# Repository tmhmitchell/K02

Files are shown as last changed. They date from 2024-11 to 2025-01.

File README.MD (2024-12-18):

<p float="center">
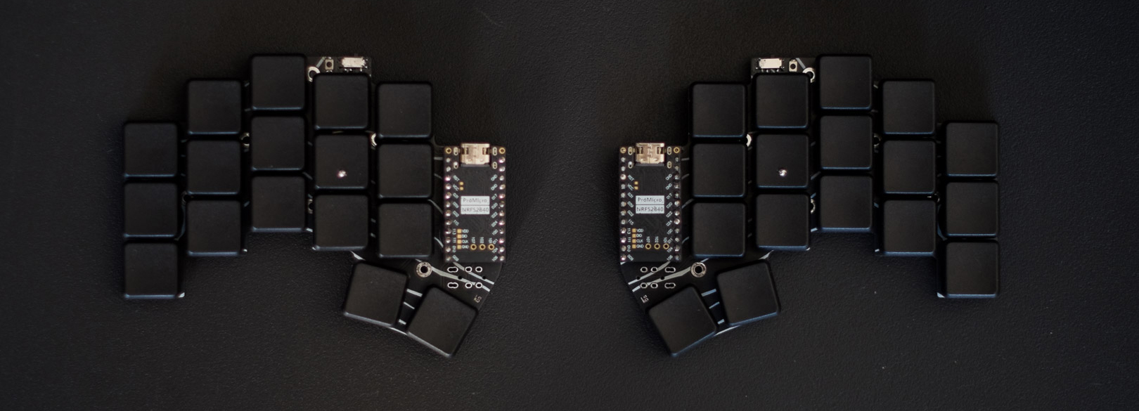
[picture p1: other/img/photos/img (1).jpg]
   
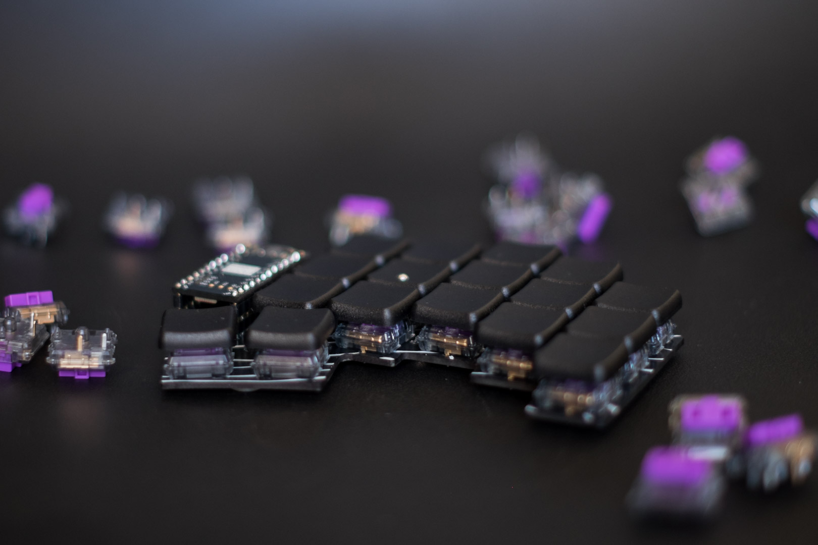
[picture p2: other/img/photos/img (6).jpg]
   
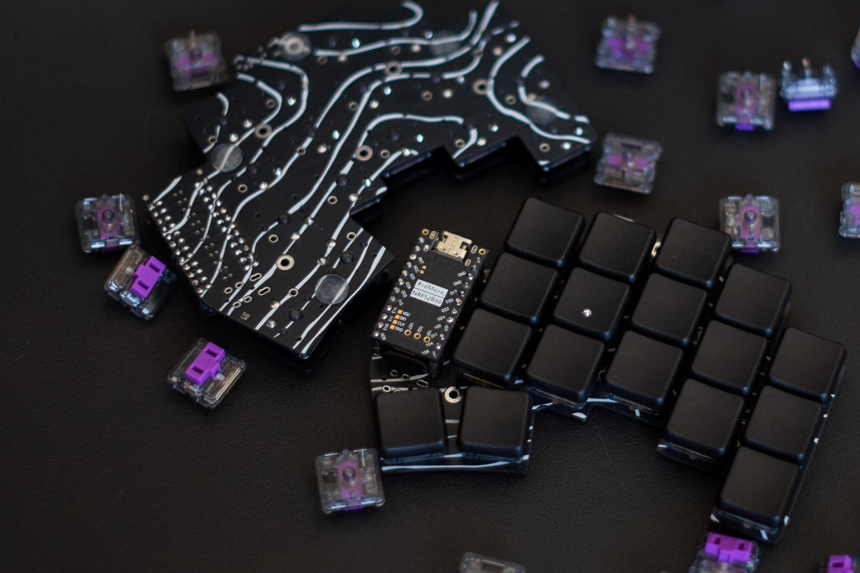
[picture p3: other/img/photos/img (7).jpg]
   
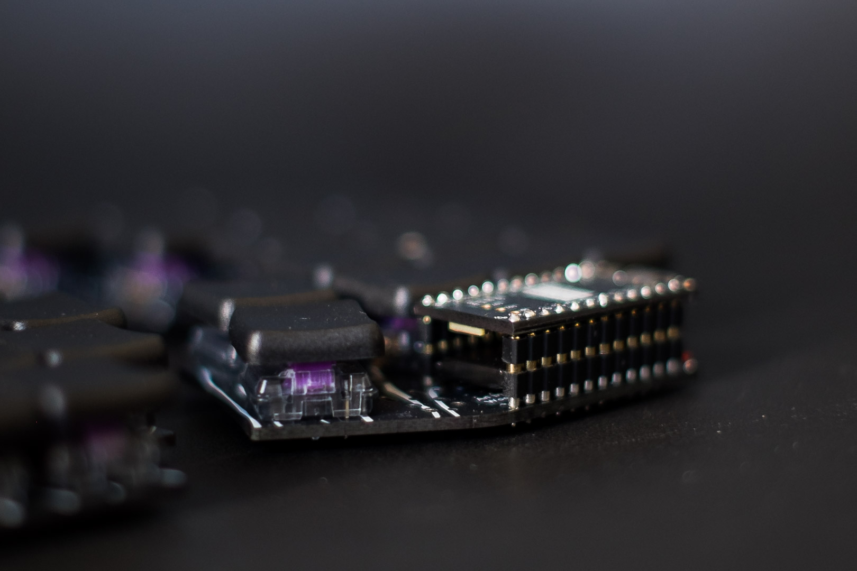
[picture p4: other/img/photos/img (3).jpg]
   
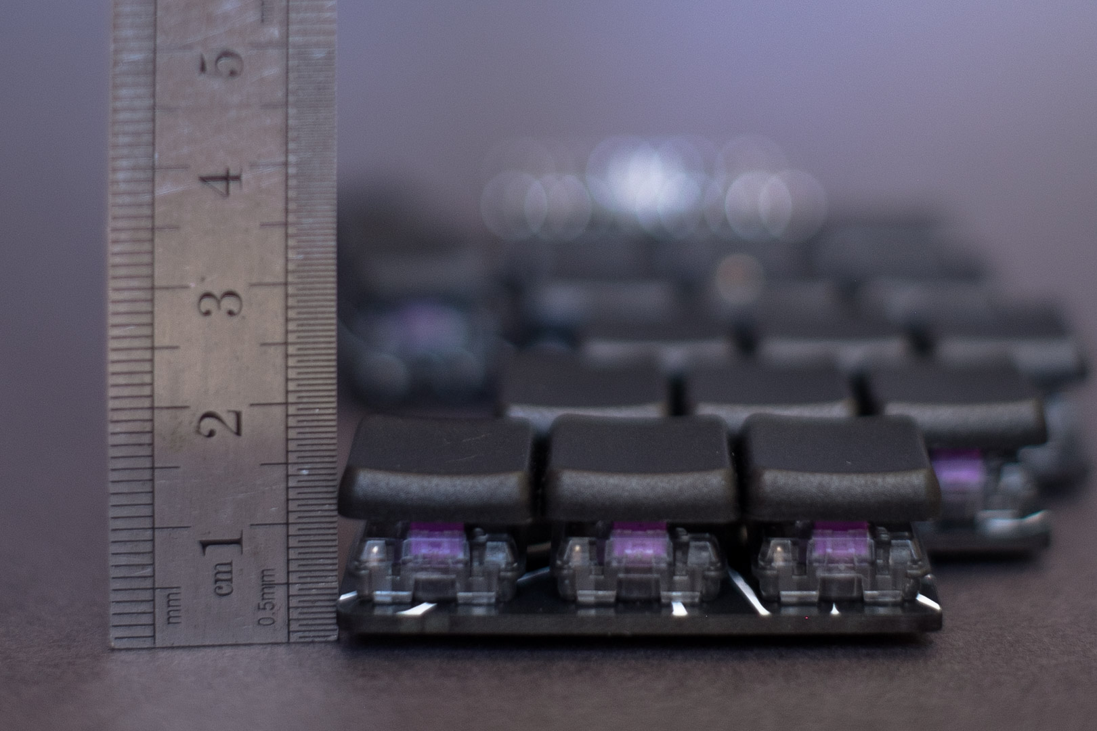
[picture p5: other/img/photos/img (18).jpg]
  
</p>

<p float="left">
  
</p>

**Less, but better.** - Dieter Rams

After seeing the [Ferris Sweep](https://github.com/davidphilipbarr/Sweep) for the first time I've fallen in love, but as a designer I cannot accept the things the way they are. So I've done some experimentation with it.

I changed the overall form of the board so it can be a little bit more compact and be a canvas for expression in the matter of case design

This is a parcial redesign of the [Ferris Sweep 2 half-swept](https://github.com/davidphilipbarr/Sweep). In other words this is a:

- 34 keys.
- Diodeless.
- Low profile.
- Non-hotswap.
- Reversible PCB.
- Column staggered.
- [Tenting puck](https://splitkb.com/products/tenting-puck) compatible.
- Wireless and wired capable.
- Choc MBK spaced (17,5mm x 16,5mm).
- Cheaper than the [cheapino](https://github.com/tompi/cheapino) (at the time of the build).

### What have been done:

- Change PCB overall form.
- Add support screw holes.
- Add teardrop on solder joints.
- Reposition of the reset and power switch.
- Do an extensive and compreensive [assembly manual](/other/manuals/k02-assembly-manual.pdf).
- Create an alternative version with `USB-C` instead of `TRRS`.
- Add commissioned art by the brazilian artist [Aline Dal Pont](https://www.instagram.com/manifesto.efemero/).
- Remove all the informative silk graphics for a better looking board.

### What I may do<sup>1</sup>:

- Change the `USB-C` location.
- Make it compatible with choc V2 switches.
- Change the `USB-C` connector to mid-mount 6p.
- Design some _minimalist_ and _low profile_ cases.
- Create an 36 keys pcb with breakpoints/mousebites.
- Add a variation with choc spacing for [CFX keycaps](https://kbd.news/CFX-keycap-1553.html) (16,5mm x 16,5mm).

> <sup>1</sup> The main reason for not doing this at the moment is the lack of financial motivation. As I have to pay for every prototype and take time off to do the development and iterations I have to be mindful of the tasks I take. If you want to help [contact me](https://www.reddit.com/user/kynikoi_/) :)

## Versions

At the moment this repo contains 2 versions, one with `TRRS` and one with `USB-C` connecting the halves. The `TRRS` connector are objectively worse than the `USB-C` for this use case, due to it introducing a risk of short in the case that the halves are unpluged with the board powered on. On the other side, the `USB-C` if not wired correctly may introduce a [risk of being connected directly to a power supply](https://docs.qmk.fm/features/split_keyboard) by mistake. I've done the bare minimum to prevent it, I wired the `GND` and `VCC` trying to follow the USB protocol. Another problem with the `USB-C` is that this implementation doesn't follow the USB protocol, it just hijack some of the data pins.

The [gerber files are in the release section.](https://github.com/anothermimich/K02/releases)
The list of materials for each version are inside of the respective folder, [USB-C](/USB-C/README.MD) and [TRRS](/TRRS/README.MD).

## Assembly

As the pcb doesn't have any information guiding the assembly, I have done an [manual with visual instructions](/other/manuals/k02-assembly-manual.pdf).

<a href="/other/manuals/k02-assembly-manual.pdf" float="center">
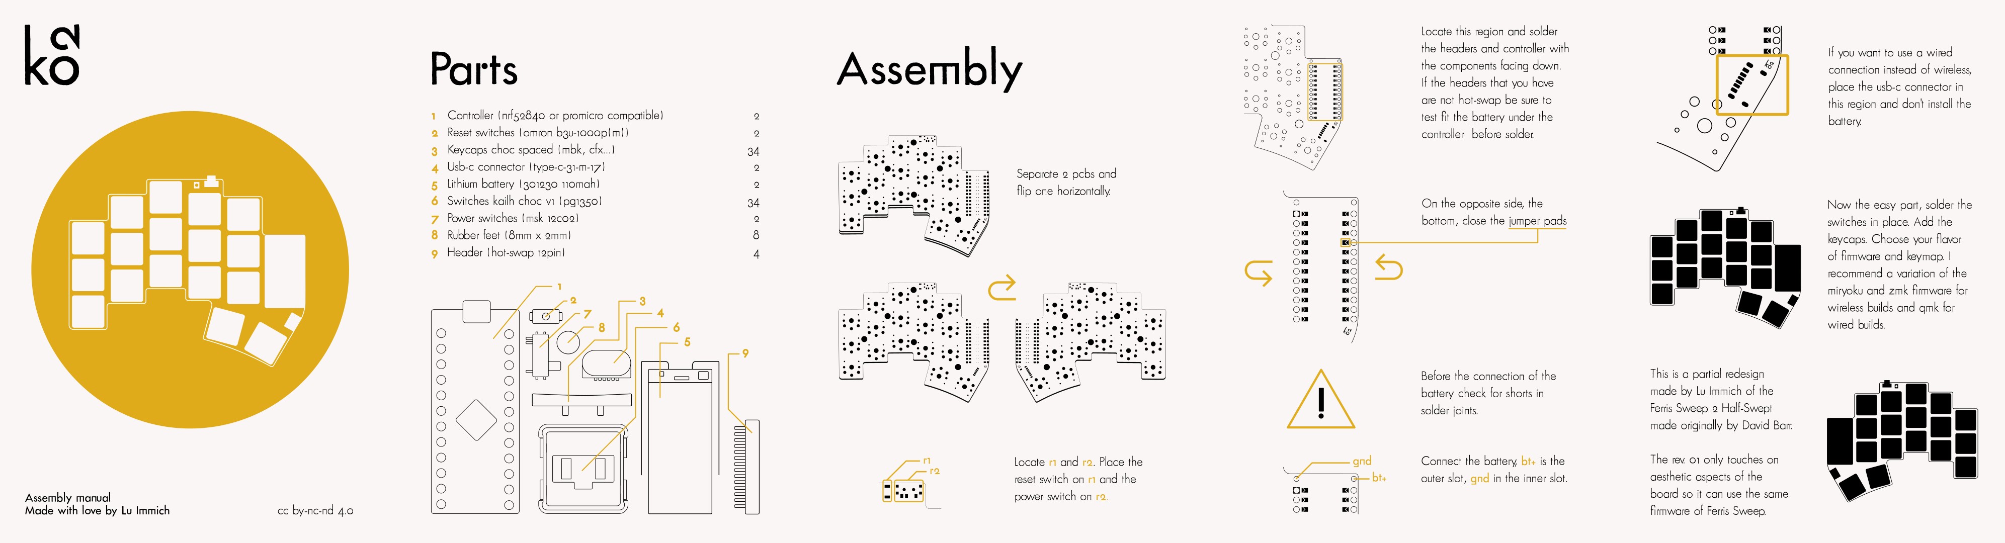
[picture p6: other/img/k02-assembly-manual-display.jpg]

</a>

## Keymap

I'm using the [Miryoku ZMK](https://github.com/manna-harbour/miryoku_zmk) keymap made by [Manna Harbour](https://github.com/manna-harbour). Bellow you can see the layout that I ended up<sup>2</sup>, if you want to replicate it you can use [compiled firmware](/other/keymaps/) or compile it from scratch with this [github workflow](https://github.com/anothermimich/miryoku_zmk/blob/master/.github/workflows/workflow-build-k02.yml), [custom_config.h](https://github.com/anothermimich/miryoku_zmk/blob/master/miryoku/custom_config.h), [cradio_left.conf](https://github.com/anothermimich/miryoku_zmk/blob/master/config/cradio_left.conf) and [cradio_right.conf](https://github.com/anothermimich/miryoku_zmk/blob/master/config/cradio_right.conf) files.

> <sup>2</sup> I'm waiting miryoku support for `.svg` export or for the maintanner to send me the files to generate it manually. [More info can be found here](https://github.com/manna-harbour/miryoku/issues/72)

## Silk art

I commissioned the work of the brazilian artist [Aline Dal Pont](https://www.instagram.com/manifesto.efemero/) for this board. You can use it as it is (with the credits) for non-commercial ends. You cannot use the work outside of this board, modify it in any way or use it commercially without the express autorization of the artist.

<p float="center">
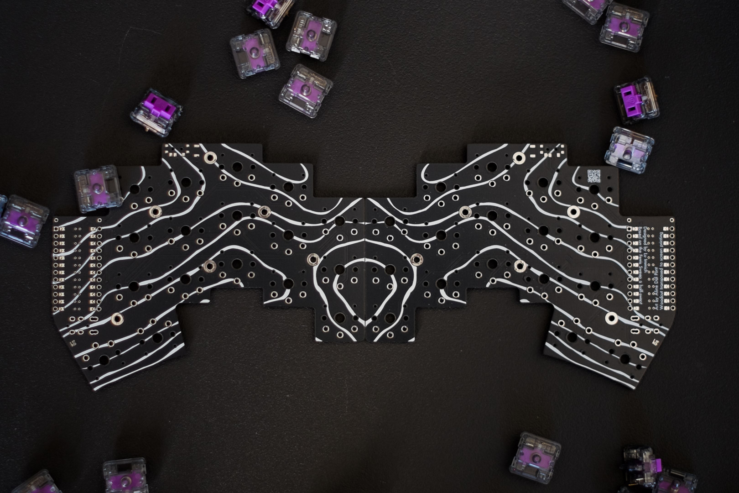
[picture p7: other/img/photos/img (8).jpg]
   
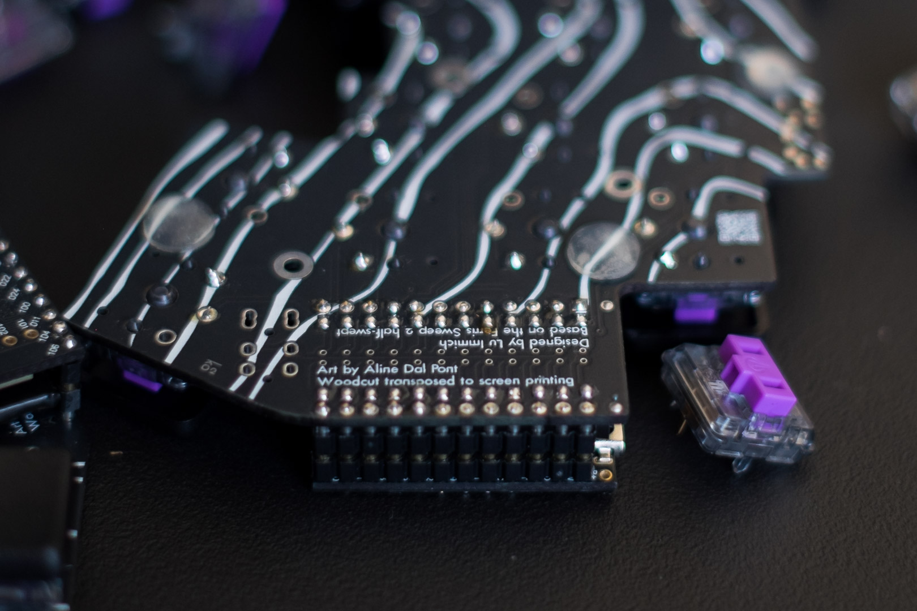
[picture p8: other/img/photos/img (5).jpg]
   
</p>

## Firmware

As this redesign had only touched on aesthetic aspects, you can use the firmware from the [Ferris Sweep](https://github.com/davidphilipbarr/Sweep).

## Disclaimer

The files in this repo may contain problems, use them at your own risk.

For the type nerds _(like me)_, the text on the PCB and logo are [FuturaRenner](https://www.fontsquirrel.com/fonts/futura-renner) aka [Formera](https://github.com/noirblancrouge/Formera).

The team behind the design of the incredible [Ferris Sweep](https://github.com/davidphilipbarr/Sweep) are: [Pierre Chevalier](https://github.com/pierrechevalier83), [David Barr](https://github.com/davidphilipbarr), [Ibnu Daru Aji](https://github.com/ibnuda/), [Duccio](https://github.com/duckyb). Without their work this parcial redesign would not be possible.

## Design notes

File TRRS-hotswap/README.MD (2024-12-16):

# Necessary Components

| Quantity | What |
| --- | --- |
| 2 | Controller ([nrf52840 or pro micro compatible](https://github.com/joric/nrfmicro/wiki/Alternatives)) |
| 34 | Switches ([Kailh PG1350/choc V1](https://cdn-shop.adafruit.com/product-files/5113/CHOC+keyswitch_Kailh-CPG135001D01_C400229.pdf)) |
| 34 | Keycaps choc v1 spaced ([MBK](https://fkcaps.com/keycaps/mbk) are the ideal size) |
| 2 | Reset switches (Omron [B3U-1000P(M)](https://omronfs.omron.com/en_US/ecb/products/pdf/en-b3u.pdf)) |
| 4 | Header ([12pin](https://github.com/joric/nrfmicro/wiki/Sockets)) |
| ? | Rubber feet (8mm x 2mm) |

## Wireless

| What | Quantity |
| ---- | --- |
| 2 | Power switches (MSK 12C02) |
| 2 | Lithium battery (301230 110mah) |

## Wired

| What | Quantity |
| ---- | --- |
| 1 | USB Cable (depends on the micro-controller used) |
| 2 | TRRS jack (PJ-320A) |
| 1 | TRRS cable |

# PCB

<p float="center">
   
   
</p>

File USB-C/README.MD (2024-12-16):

# Assembly manual

Check the [assembly manual](https://github.com/anothermimich/K02/blob/main/other/manuals/k02-assembly-manual.pdf) for a detailed guide on the process of putting this board together.

<a href="/other/manuals/k02-assembly-manual.pdf" float="center">

</a>

# Production files

The [gerber files can be found in the release section.](https://github.com/anothermimich/K02/releases)

# Necessary Components

| Quantity | What |
| --- | --- |
| 2 | Controller ([nrf52840 or pro micro compatible](https://github.com/joric/nrfmicro/wiki/Alternatives)) |
| 34 | Switches ([Kailh PG1350/choc V1](https://cdn-shop.adafruit.com/product-files/5113/CHOC+keyswitch_Kailh-CPG135001D01_C400229.pdf)) |
| 34 | Keycaps choc v1 spaced ([MBK](https://fkcaps.com/keycaps/mbk) are the ideal size) |
| 2 | Reset switches (Omron [B3U-1000P(M)](https://omronfs.omron.com/en_US/ecb/products/pdf/en-b3u.pdf)) |
| 4 | Header ([12pin](https://github.com/joric/nrfmicro/wiki/Sockets)) |
| 10 | Rubber feet (8mm x 2mm) |

## Wireless

| What | Quantity |
| ---- | --- |
| 2 | Power switches (MSK 12C02) |
| 2 | Lithium battery (301230 110mah) |

## Wired

| What | Quantity |
| ---- | --- |
| 2 | USB-C connector ([TYPE-C-31-M-17](https://www.lcsc.com/datasheet/lcsc_datasheet_2410010030_Korean-Hroparts-Elec-TYPE-C-31-M-17_C283540.pdf)) |
| 1 | USB-C cable |

# PCB

<p float="center">
   
   
</p>

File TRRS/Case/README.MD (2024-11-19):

# Acrylic case

This case has two versions. The **full** version will add 2mm to the board height. The **lite** version don't add any height to the board.

For both versions the laser kerf need to be ajusted. You can use inkscape offset path effect to do that based on the kerf value provided by the manufacture.

## Full

| Quantity | What |
| --- | --- |
| 2 | Laser cut acrylic 2mm back |
| 2 | Laser cut acrylic 2mm middle |
| 2 | Heat insert M2(OD 3.2mm) 2mm lenght |

## Lite

| Quantity | What |
| --- | --- |
| 2 | Laser cut acrylic 2mm |
| 2 | Heat insert M2(OD 3.2mm) 2mm lenght |

## How to make it better

You can add recess for the rubber feet. The best option is to do this based on the rubber feet you find, i suggest 10mm x 3mm.

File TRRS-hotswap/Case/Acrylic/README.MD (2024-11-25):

# Acrylic case

This case has two versions:

- The **one-piece** make use of laser engraving and just one sheet of at least 3mm thick acrylic, in the configuration it will add 1mm to the board height
- The **two-pieces** case are unfinished.

**I've noted that when opened in some softwares the overall size of the case changes, the ideal size is 109.4mm.**

## One-piece

| Quantity | What |
| --- | --- |
| 2 | Laser engraved acrylic 3mm |
| 12 | Heat insert M2(OD 3.2mm) 2mm lenght |
| 12 | Screw M2 4mm lenght |
| 12 | Brass washer M2 0.4mm height |
| 12 | Neodymium magnets 5mm x 5mm x 2mm |

The parts of the archive inked in black need to be engraved in 2mm deep. As the people that do laser cut usually don't know their exact kerf width I assumed something around [0.18mm](https://cutlasercut.com/drawing-resources/expert-tips/laser-kerf/) in the heat inserts (2.7mm + (0.18mm\*2) = 3.06mm). All the remaining cuts are not ajusted for kerf.

## Two-pieces - Unfinished

| Quantity | What |
| --- | --- |
| 2 | Laser cut acrylic 2mm back |
| 2 | Laser cut acrylic 2mm middle |
| 12 | Heat insert M2(OD 3.2mm) 2mm lenght |
| 12 | Screw M2 5mm lenght |

## How to make it better

The laser kerf width can be ajusted to get a more precise finish. You can use inkscape offset path effect to do that based on the kerf value provided by the manufacture.

You can add recess for the rubber feet. The best option is to do this based on the rubber feet you find.

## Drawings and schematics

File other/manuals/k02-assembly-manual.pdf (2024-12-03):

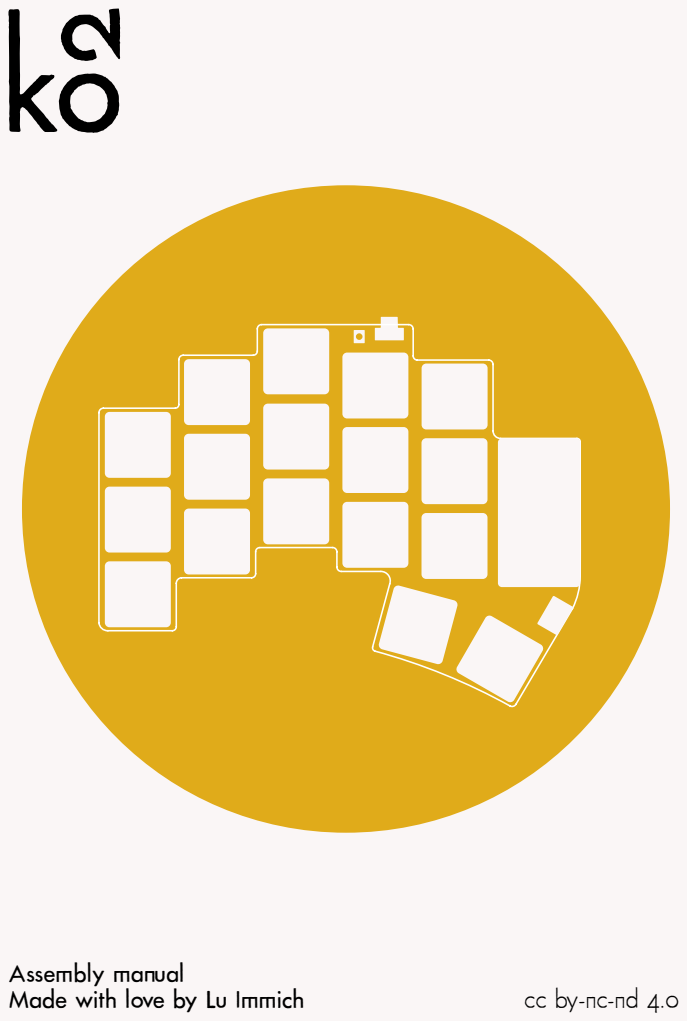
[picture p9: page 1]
Assembly manual; Made with love by Lu Immich

# Parts

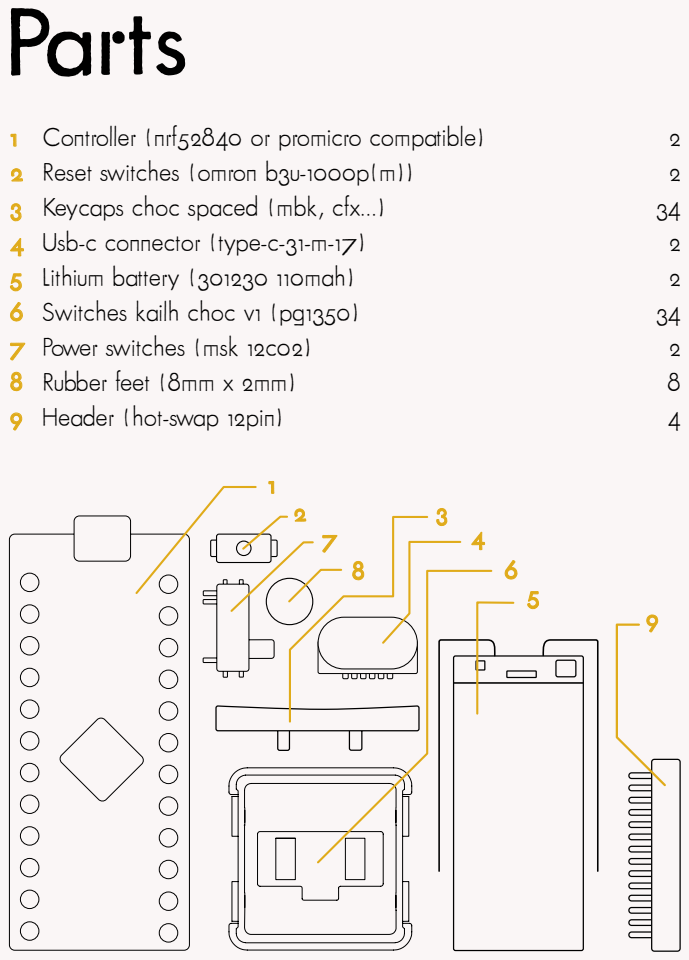
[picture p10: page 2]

Controller (nrf52840 or promicro compatible)
Reset switches (omron b3u-1000p(m))
Keycaps choc spaced (mbk, cfx...)
Usb-c connector (type-c-31-m-17)
Lithium battery (301230 110mah)
Switches kailh choc v1 (pg1350)
Power switches (msk 12c02)
Rubber feet (8mm x 2mm)
Header (hot-swap 12pin)

# Assembly

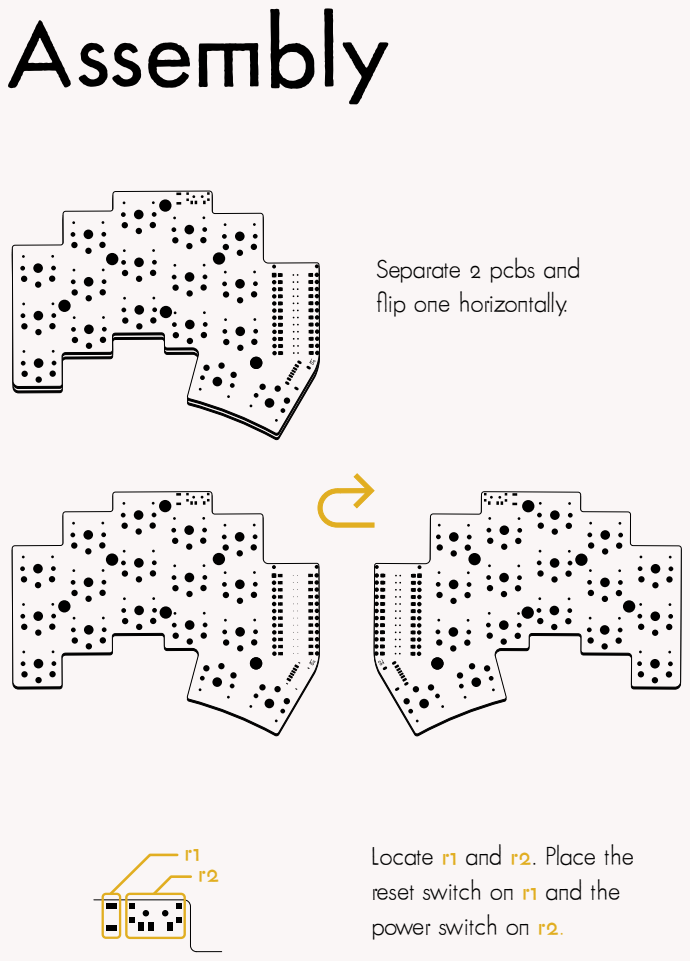
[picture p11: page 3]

Separate 2 pcbs and
flip one horizontally.

Locate r1 and r2. Place the
reset switch on r1 and the
power switch on r2.

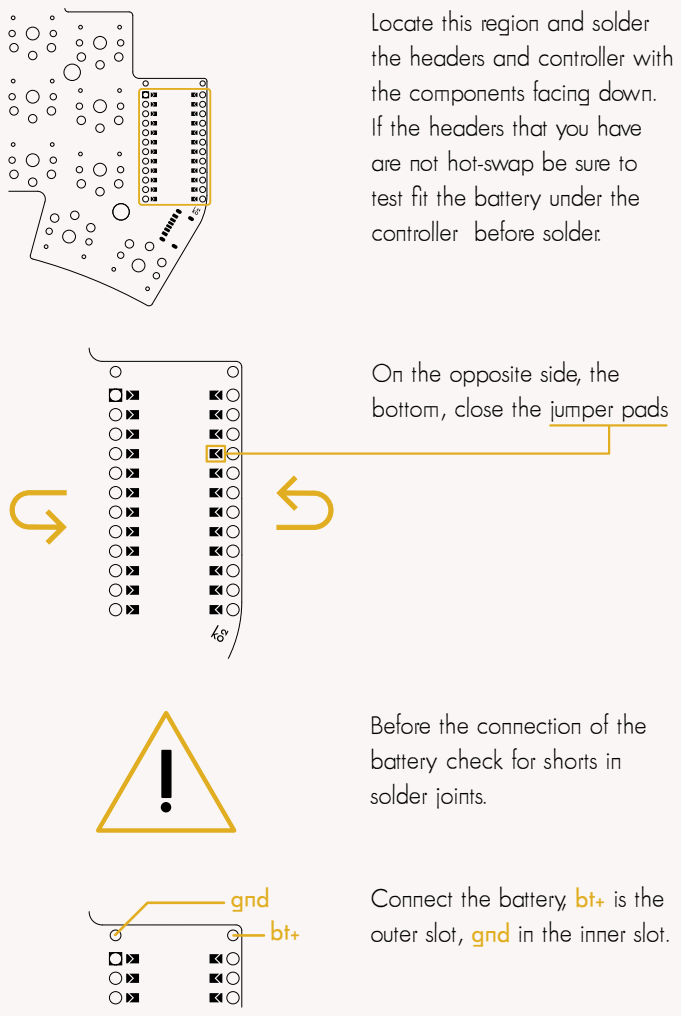
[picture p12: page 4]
gnd

Locate this region and solder
the headers and controller with
the components facing down.
If the headers that you have
are not hot-swap be sure to
test fit the battery under the
controller before solder.

On the opposite side, the
bottom, close the jumper pads

Before the connection of the
battery check for shorts in
solder joints.

Connect the battery, bt+ is the
outer slot, gnd in the inner slot.

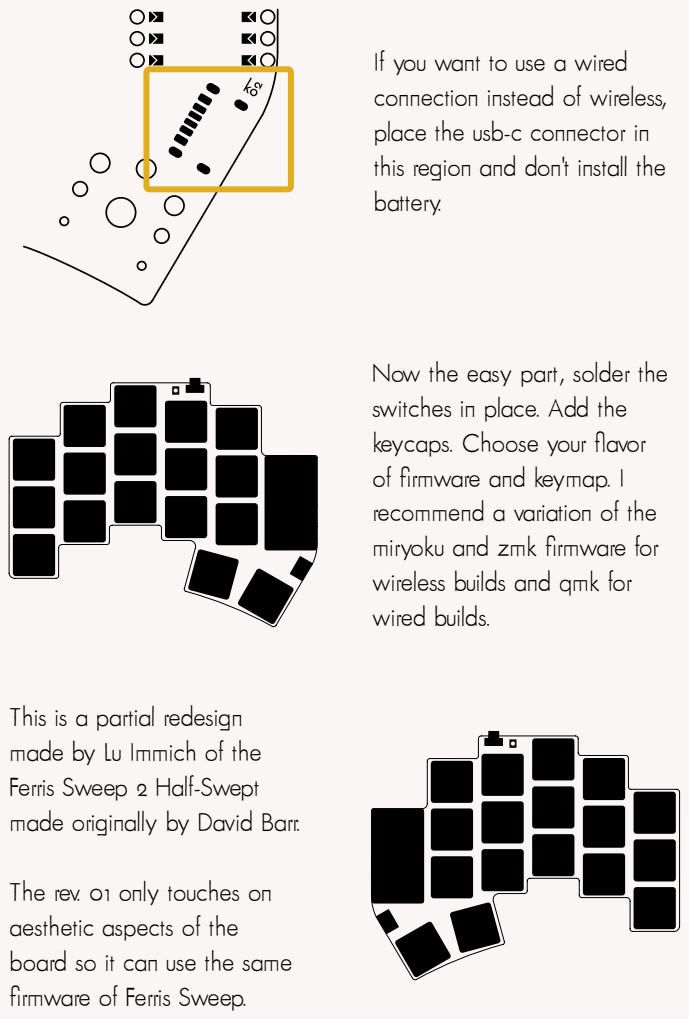
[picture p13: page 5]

If you want to use a wired
connection instead of wireless,
place the usb-c connector in
this region and don't install the
battery.

Now the easy part, solder the
switches in place. Add the
keycaps. Choose your flavor
of firmware and keymap. I
recommend a variation of the
miryoku and zmk firmware for
wireless builds and qmk for
wired builds.

This is a partial redesign
made by Lu Immich of the
Ferris Sweep 2 Half-Swept
made originally by David Barr.

The rev. 01 only touches on
aesthetic aspects of the
board so it can use the same
firmware of Ferris Sweep.

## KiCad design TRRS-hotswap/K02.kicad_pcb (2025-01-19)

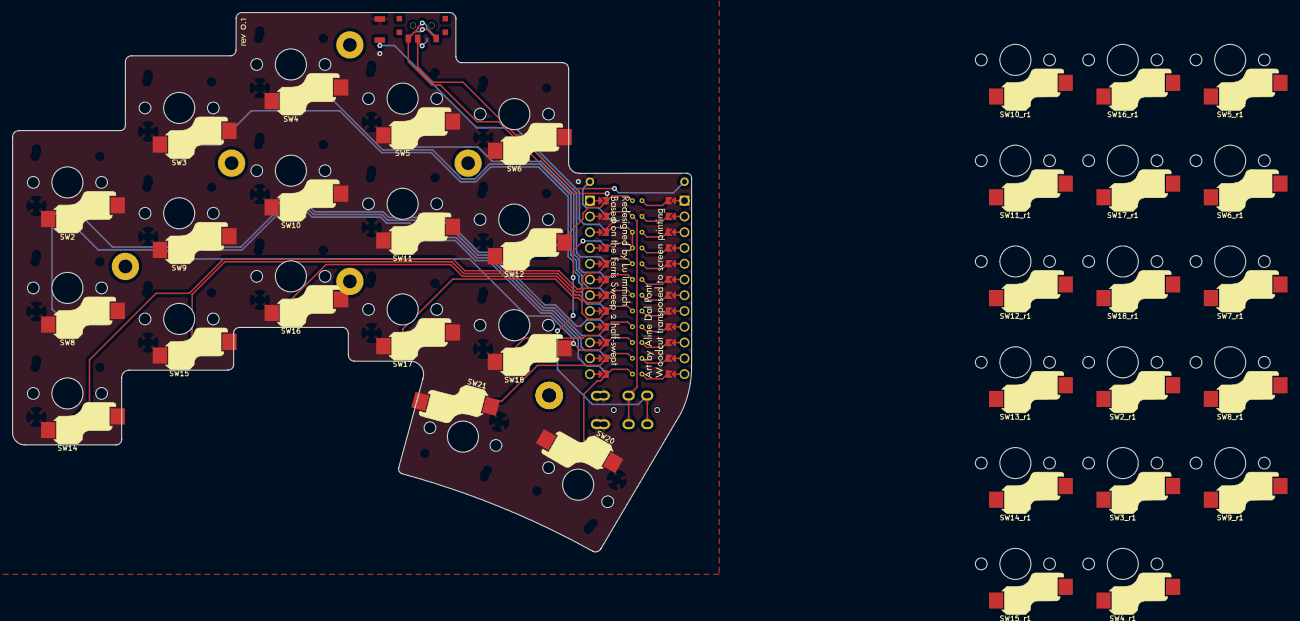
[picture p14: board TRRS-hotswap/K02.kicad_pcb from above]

Board: 2 copper layers, 109.4 x 86.9 mm, 40 parts (0 on the bottom side), 23 nets.

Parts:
Bat+r1: MountingHole_Pad; 1pin_conn
BatGND1: MountingHole_Pad; 1pin_conn
J2: AudioJack4dpb; TRRS-PJ-DPB2
POWER SW: SW_SPDT; SPDT_C128955
RSW2: SW_Push; Tactile-Switch_SMT
SW2, SW2_r1, SW3, SW3_r1, SW4, SW4_r1, SW5, SW5_r1, SW6, SW6_r1, SW7_r1, SW8, SW8_r1, SW9, SW9_r1, SW10, SW10_r1, SW11, SW11_r1, SW12, SW12_r1, SW13_r1, SW14, SW14_r1, SW15, SW15_r1, SW16, SW16_r1, SW17, SW17_r1, SW18, SW18_r1, SW20, SW21: SW_Push; keyswitch_choc12_hotswap_1u
U1: ProMicro-kbd; ProMicro_jumpers_facedown

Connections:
BT+_r: Bat+r1.1, POWER SW.2
Switch1: SW2.1, U1.10
Switch2: SW3.1, U1.17
Switch3: SW4.1, U1.18
Switch4: SW5.1, U1.19
Switch5: SW6.1, U1.20
Switch6: SW8.1, U1.16
Switch7: SW9.1, U1.15
Switch8: SW10.1, U1.14
Switch9: SW11.1, U1.13
Switch10: SW12.1, U1.1
Switch11: SW14.1, U1.5
Switch12: SW15.1, U1.6
Switch13: SW16.1, U1.7
Switch14: SW17.1, U1.8
Switch15: SW18.1, U1.9
Switch16: SW20.1, U1.11
Switch17: SW21.1, U1.12
Switch18: J2.R1, U1.2
gnd: BatGND1.1, J2.S, J2.T, RSW2.1, RSW2.2, SW2.2, SW2_r1.2, SW3.2, SW3_r1.2, SW4.2, SW4_r1.2, SW5.2, SW5_r1.2, SW6.2, SW6_r1.2, SW7_r1.2, SW8.2, SW8_r1.2, SW9.2, SW9_r1.2, SW10.2, SW10_r1.2, SW11.2, SW11_r1.2, SW12.2, SW12_r1.2, SW13_r1.2, SW14.2, SW14_r1.2, SW15.2, SW15_r1.2, SW16.2, SW16_r1.2, SW17.2, SW17_r1.2, SW18.2, SW18_r1.2, SW20.2, SW21.2, U1.3, U1.4, U1.23
raw: POWER SW.3, U1.24
reset: RSW2.1, RSW2.2, U1.22
vcc: J2.R2, U1.21

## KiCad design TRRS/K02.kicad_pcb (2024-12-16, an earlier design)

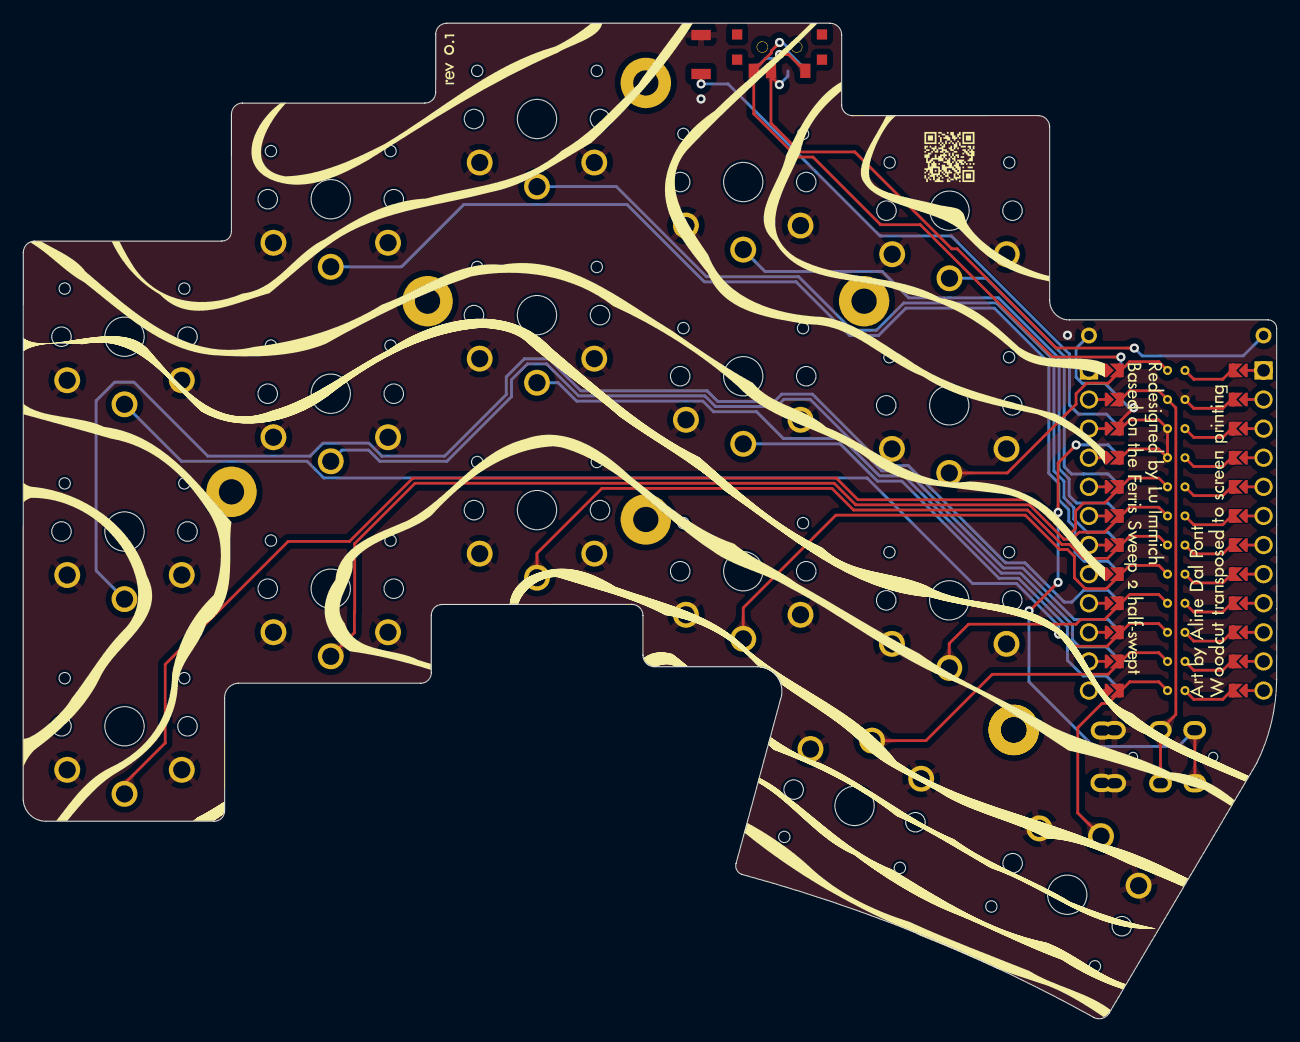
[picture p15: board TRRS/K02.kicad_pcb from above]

Board: 2 copper layers, 109.4 x 86.9 mm, 23 parts (0 on the bottom side), 23 nets.

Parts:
B+: MountingHole_Pad; 1pin_conn
B-: MountingHole_Pad; 1pin_conn
J2: AudioJack4dpb; TRRS-PJ-DPB2
POWER SW: SW_SPDT; SPDT_C128955
RSW2: SW_Push; Tactile-Switch_SMT
SW1, SW2, SW3, SW4, SW5, SW6, SW7, SW8, SW9, SW10, SW11, SW12, SW13, SW14, SW15, SW16, SW17: SW_Push; SW_PG1350_rev_DPB
U1: ProMicro-kbd; ProMicro_jumpers_facedown

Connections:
BT+_r: B+.1, POWER SW.2
Switch1: SW1.1, U1.10
Switch2: SW2.1, U1.17
Switch3: SW3.1, U1.18
Switch4: SW4.1, U1.19
Switch5: SW5.1, U1.20
Switch6: SW6.1, U1.16
Switch7: SW7.1, U1.15
Switch8: SW8.1, U1.14
Switch9: SW9.1, U1.13
Switch10: SW10.1, U1.1
Switch11: SW11.1, U1.5
Switch12: SW12.1, U1.6
Switch13: SW13.1, U1.7
Switch14: SW14.1, U1.8
Switch15: SW15.1, U1.9
Switch16: SW16.1, U1.11
Switch17: SW17.1, U1.12
Switch18: J2.R1, U1.2
gnd: B-.1, J2.S, J2.T, RSW2.1, RSW2.2, SW1.2, SW2.2, SW3.2, SW4.2, SW5.2, SW6.2, SW7.2, SW8.2, SW9.2, SW10.2, SW11.2, SW12.2, SW13.2, SW14.2, SW15.2, SW16.2, SW17.2, U1.3, U1.4, U1.23
raw: POWER SW.3, U1.24
reset: RSW2.1, RSW2.2, U1.22
vcc: J2.R2, U1.21

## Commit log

2024-11-09 new version
    [half-swept.kicad_pcb, half-swept.kicad_sch]
2024-11-14 new new new
    [half-swept.kicad_pcb]
2024-11-15 change in name sistem
    [K02.kicad_pcb, K02.kicad_sch, bom.csv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]
2024-11-15 agr vai
    [K02.kicad_pcb]
2024-11-16 with gerbers
    [K02.kicad_pcb]
2024-11-16 added case
2024-11-17 fix on the rights
    [K02.kicad_pcb]
2024-11-18 case update
2024-11-22 the case is ready
2024-11-22 now with magnets
2024-12-16 regenerate gerber
    [K02-USB-C.kicad_pcb, K02.kicad_pcb]
2025-01-19 Begin work on hotswap version
    [K02.kicad_pcb, K02.kicad_sch]
